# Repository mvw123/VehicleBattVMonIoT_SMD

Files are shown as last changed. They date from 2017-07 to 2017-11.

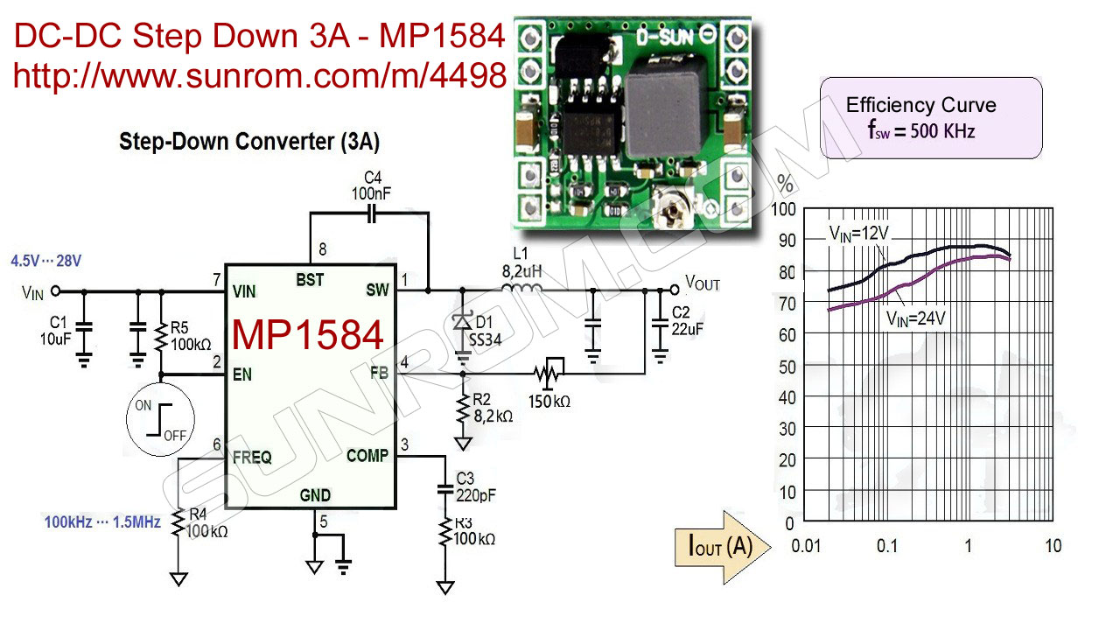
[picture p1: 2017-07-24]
CADB/MP1584-schematic.jpg

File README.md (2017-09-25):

Vehicle battery voltage monitor IoT SMD
=======================================

Vehicle battery voltage monitor IoT. Measures the voltage of a 12V car battery. Sends this to a receiver device which pushes the data to the cloud.

This PCB is designed to fit in the car strapped between the battery terminals. It uses either a LoRA RFM95 module, or a sub Ghz modules RFM69HCW module. Other parts of the design mostly use low cost modules to reduce the hand assembly time. Some through hole components, SMD 0805 and SMD diodes require hand assembly.

Designed using Eagle cad 7.5.0 light.

Incorporates support for:- 
* Arduino Pro Mini, 3.3V, 8MHz version only. (5V version will damage circuit)
* RFM69HCW or RFM95W/96W/97W/98W module
* SMA 50 ohm antenna connector
* 16 bit ADC module TI ADS1115
* Sensirion SHT31 temperature/humidity sensor module
* DC-DC converter
* Fuse and reverse voltage protection
* [Optional] RGB LED to visually indicate voltage levels
* [Optional] EUI-64 LoRA node identity chip for debug
* [Optional] Winbond flash storage
* [Optional] OLED display interface for debug purposes
* [Optional] HM-10 Bluetooth LE module carrier footprint

CAD B - [WIP]
=============

Not released yet, needs CAD updates. 

CAD A - [FAULTY]
===========================

Board has CAD issues, see issues list. needed some wiring and re-work. 
Board released for manufacture 3 Aug 2017
Software partially written

MVW
www.guvvy.co.uk

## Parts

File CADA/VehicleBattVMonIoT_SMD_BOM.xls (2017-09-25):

Qty | Value | Device | Package | Parts | Description | MF | MPN | OC_FARNELL | Price | OC_NEWARK | PROD_ID | Digikey | Other | Price
3 | 100uF, 25V, 85C | CAP_POLPTH1 | CPOL-RADIAL-100UF-25V | C1, C4, C5 | Capacitor Polarized | MULTICOMP | MCUMR25V107M8X5 | 1870940
9 | 1uF, 0805, 25V, X5R | C-EUC0805 | C0805 | C2, C3, C6, C7, C9, C10, C11, C12, C13 | CAPACITOR, European symbol | MULTICOMP | MC0805X105K250CT | 2320832
1 | 1NF, 0805, 16V, X5R |  | C0805 | C8 | CAPACITOR, European symbol | MULTICOMP | MCSH21B102K160CT | 1856432
1 | MBRA340T3 | MBRA340T3 | SMA | D1 | Surface Mount Schottky Power Rectifier | ON SEMICONDUCTOR | MBRA340T3G | 1431078
1 | 1N4148W | DIODESOD-323F | SOD-323F | D11 | Diode | MULTICOMP | 1N4148WS. | 1466524
8 | MBR0520LT | MBR0520LT | SOD123 | D2, D3, D4, D5, D6, D7, D8, D10 | SCHOTTKY BARRIER RECTIFIER | Taiwan semi | B0520LW | 1863141 | £0.028 |  |  |  | BAT42W+ at farnell is £0.069 in 10 off qty if the series power diode can be dropped (which is can)
1 | WS2812B | WS2812B | WS2812B | D9 | WS2812B - Intelligent control LED integrated light source |  |  | - |  |  |  |  | See ebay
1 | Multicomp MC36219 | PTCFUSE-1812 | 1812 | F1 | PTC fuses, resettable thermistors | MULTICOMP | MC36219. | 1861164
1 | 24AA02E64 | 24AA00OT | SOT23-5L | IC1 | Serial EEPROM | MICROCHIP | 24AA00T-I/OT | 1331264 |  | 89H3038
1 | LM1117 | V_REG_LM1117SOT223 | SOT223 | IC3 | Voltage Regulator LM1117 | STMICROELECTRONICS | LD1117S33TR | 1202826 |  |  | VREG-08170
1 | HM-10 MODULE | CON_HEADER_1X06-SMD-RIGHT-ANGLED | M1X6_MALE_RIGHT_ANGLED_SMD | J1 |  |  |  | - |  |  |  |  | See ebay, only buy original was 2 crystals
1 | SHT31 MODULE | PINHD-1X4 | 1X04 | JP1 |  |  |  | - |  |  |  |  | See ebay
1 | OLED MODULE | PINHD-1X4 | 1X04 | JP2 |  |  |  | - |  |  |  |  | See ebay
1 | MSS7341 | MSS7341 | MSS7341 | L1 |  | COILCRAFT | MSS7341-683MLD | 2288678
1 | ARDUINO-PRO-MINI-3.3V#APC | ARDUINO-PRO-MINI-3.3V#APC | ARDUINO-PRO-MINI#APC | M1 | Arduino Pro Mini (and compatible devices) with angle programming connector |  |  | - |  |  |  |  | See ebay
6 | 10k, 5% | R-EU_R0805 | R0805 | R1, R2, R3, R4, R6, R7 | RESISTOR, European symbol | MULTICOMP | MC01W0805510K | 9333720
2 | 22k, 1% | R-EU_R0805 | R0805 | R10, R11 | RESISTOR, European symbol | WELWYN | WCR0805-22KFI | 1099809
1 | 1k, 5% | R-EU_R0805 | R0805 | R5 | RESISTOR, European symbol | WELWYN | WCR0805-1K0FI | 1099800
2 | 100k, 1% | R-EU_R0805 | R0805 | R8, R9 | RESISTOR, European symbol | YAGEO (PHYCOMP) | RC0805FR-07100KL | 9237879
1 | ADS1115 MODULE | MA10-1W | MA10-1W | SV1 |  |  |  | - |  |  |  |  | See ebay
1 | DC-DC-STEP-DOWN-MP1584 | DC-DC-STEP-DOWN-MP1584 | DC-DC-STEP-DOWN-MP1584 | U1 | DC/DC Step-Down Regulator based on MP1584 chip |  |  | - |  |  |  |  | See ebay
1 | RFM9xW | RFM9xW | RFM69HCW-XXXS2 | U3 | RFM69HCW, or LoRA RFM9xW. Choose frequency appropriate for your location | Hope RF | Frequency dependent | - |  |  |  |  | See list at bottom of BOM
1 | W25Q80DVSNIG | SPI_FLASH-X25XXSMD | SO08 | U4 | 8pin SPI Flash series x25xx. Works with devices like W25X32 and BR25L32, may need software driver for specific part | Winbond | W25Q80DVSNIG | not available at farnell |  |  |  | W25Q80DVSNIG CT-ND | See ebay
1 | BU-SMA-G | BU-SMA-G | BU-SMA-G | X1 | FEMALE SMA CONNECTOR | AMP - TE CONNECTIVITY | 5-1814400-1 | 1248989
 | Antenna |  |  | Mech1 | Frequency dependent |  |  |  |  |  |  |  | See ebay, ali express etc
 | Case |  |  | Mech2 | Off the shelf, donor, or custom check fire retardancy ratings |  |  |  |  |  |  |  | Donor: Maplin Electronics N70NF | £0.99
 | Screws M2.5 | DTRNSE 1207 M2.5 10 |  | Mech3 | 10mm nylon M2.5 screw |  |  | 2472698
 | Posts | DTRDLCBST-1-01 |  | Mech4 | The DTRDLCBST-1-01 is a PCB Mini Support Post made of PA 66. 2.54 ±0.08mm Hole diameter 1.63mm Panel thickness |  |  | 2472885
 | Washer | DTRNWE 34815 M2.5 |  | Mech5 | M2.5 washer |  |  | 2472663
 | Nuts | Duratool 1110025 |  | Mech6 | Nylon nut pack of 50 |  |  | 7016931
 | Wire |  |  | Mech7 | Automotive wire 2mm^2, check fire retardancy ratings |  |  |  |  |  |  |  | Ebay or Source from hackspace initially
 | Crimps |  |  | Mech7 | Size? |  |  |  |  |  |  |  | B&Q for initial samples
 | Crimp tool |  |  | Mech8 | Do I have one in old toolboxes??? |  |  |  |  |  |  |  | B&Q for initial samples
0 | TP_1MM_TH";"TP_1MM_TH";"TP_1MM_TH | TP1, TP2, TP3, TP4, TP5, TP6, TP7, TP8 | Bare copper test points for troubleshooting or ICT |  |  | unknown
0 | POS | 3,81/1,4 | 3,81/1,4 | PAD1 | THROUGH-HOLE PAD
0 | NEG | 3,81/1,4 | 3,81/1,4 | PAD2 | THROUGH-HOLE PAD
0 | MOUNT-HOLE2.8 | MOUNT-HOLE2.8 | 2,8 | H2, H3, H4, H5 | MOUNTING HOLE with drill center marker
 | 868MHz
 | Antenna
 | RFM95W-868S2

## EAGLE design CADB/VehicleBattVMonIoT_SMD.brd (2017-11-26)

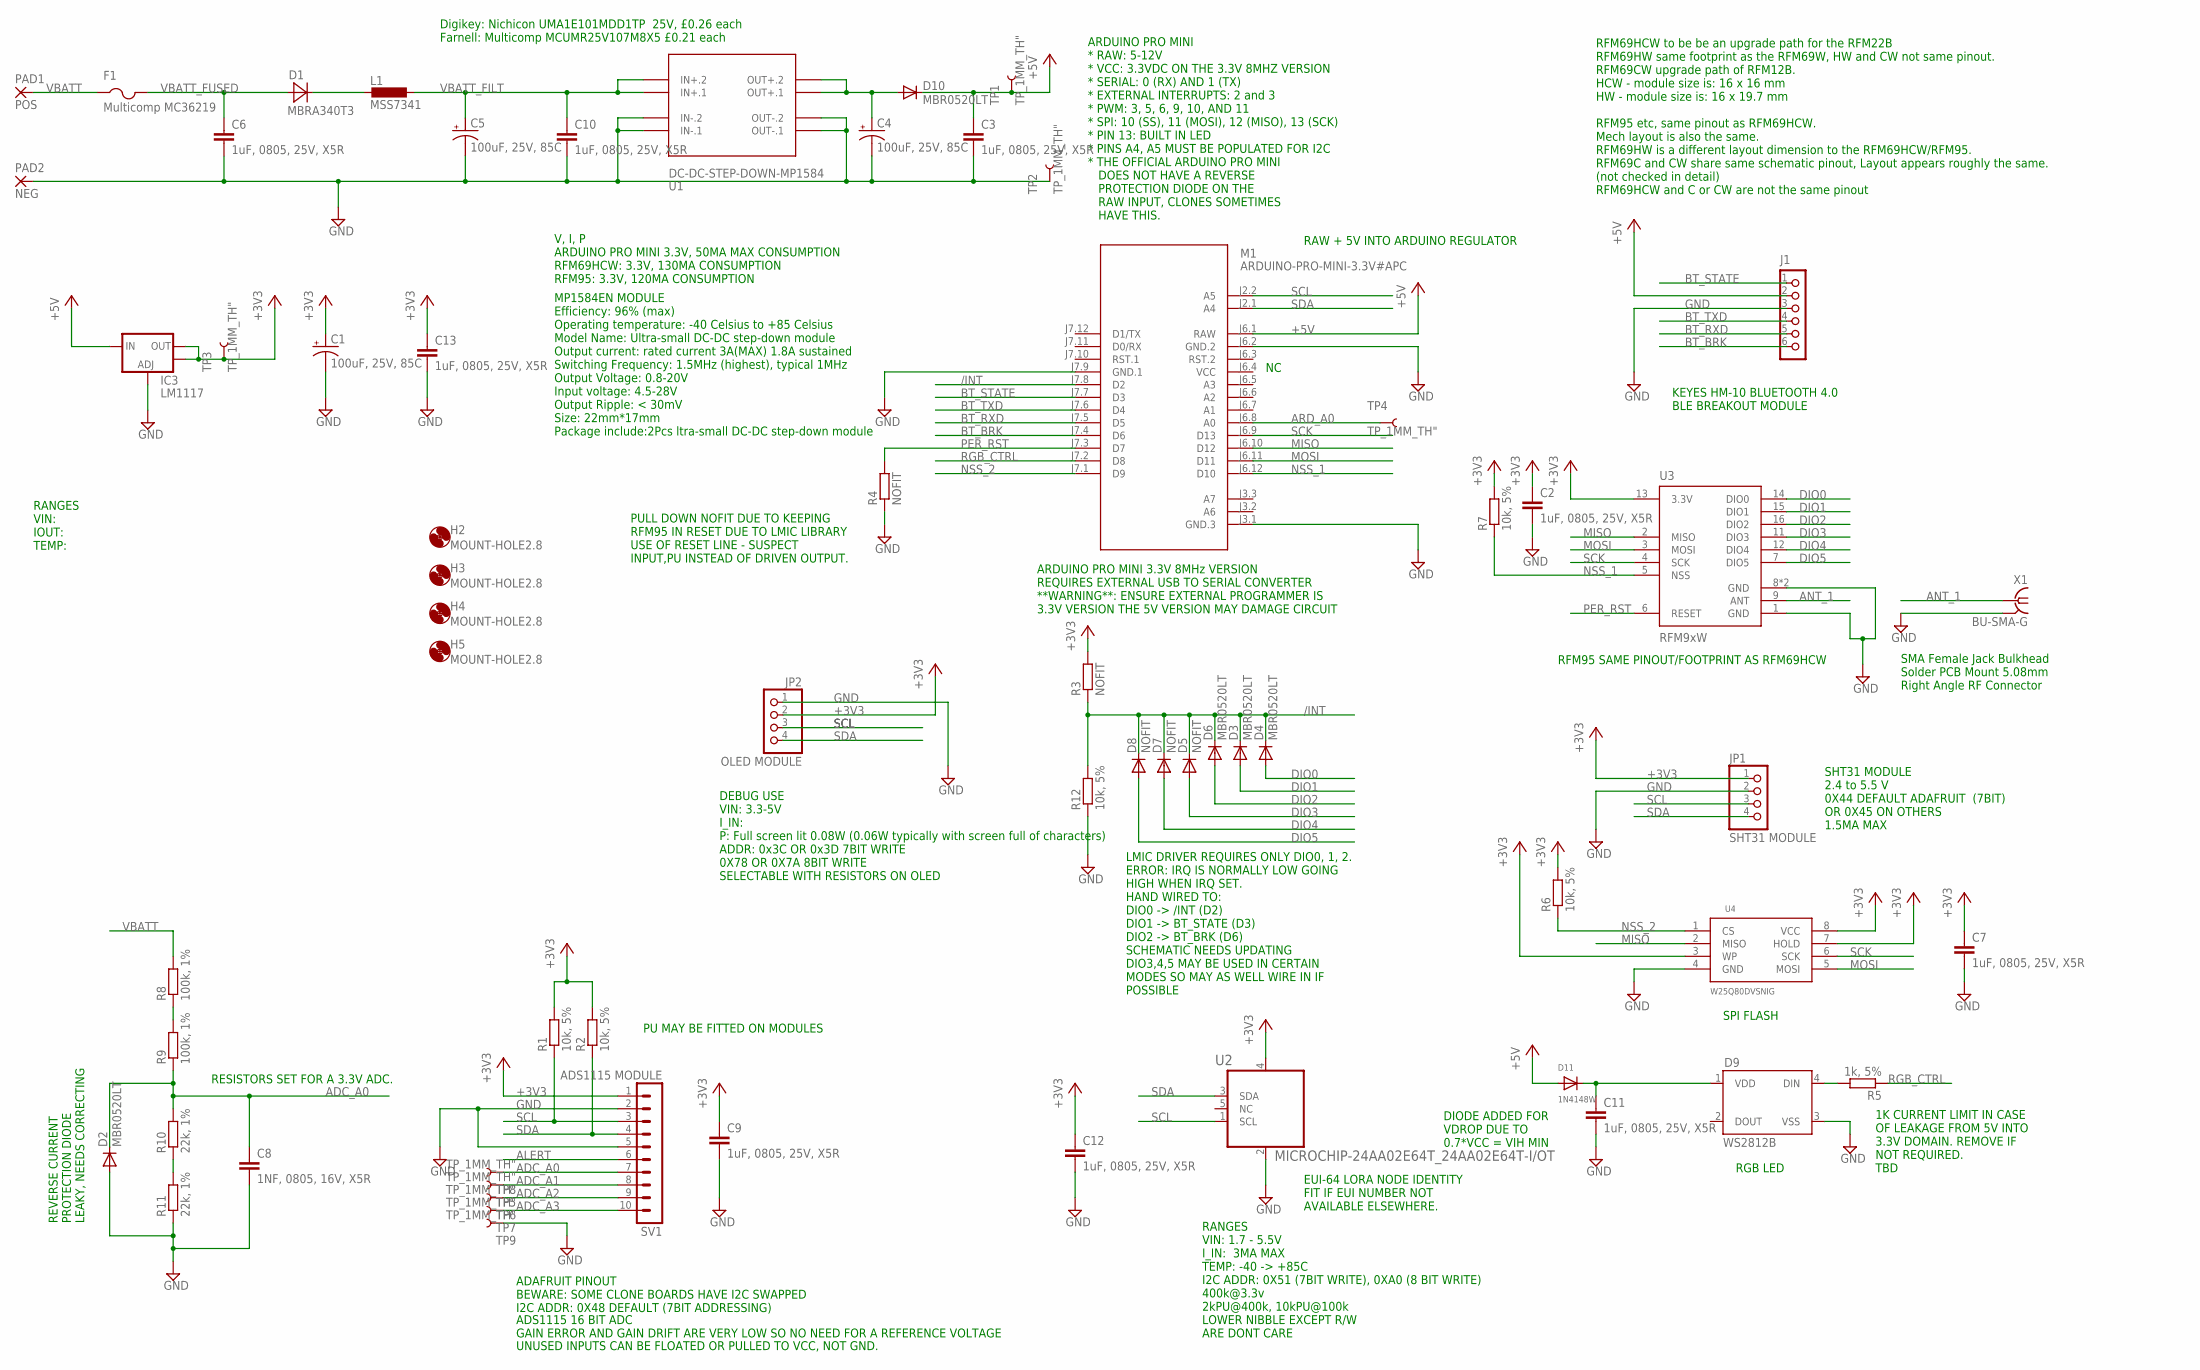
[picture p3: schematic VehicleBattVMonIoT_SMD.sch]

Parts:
C1, C4, C5: 100uF, 25V, 85C; CPOL-RADIAL-100UF-25V; MPN MCUMR25V107M8X5
C2, C3, C6, C7, C9, C10, C11, C12, C13: 1uF, 0805, 25V, X5R; C0805; MPN MC0805X105K250CT
C8: 1NF, 0805, 16V, X5R; C0805; MPN MCSH21B102K160CT
D1: MBRA340T3; SMA; MPN MBRA340T3G
D2, D3, D4, D6, D10: MBR0520LT; SOD123; MPN B0520LW-7-F
D5, D7, D8: NOFIT; SOD123; MPN B0520LW-7-F
D9: WS2812B
D11: 1N4148W; SOD-323F; MPN 1N4148WS.
F1: Multicomp MC36219; 1812; MPN MC36219.
H2, H3, H4, H5: MOUNT-HOLE2.8; 2,8
IC3: LM1117; SOT223; MPN LD1117S33TR
J1: HM-10 MODULE; M1X6_MALE_RIGHT_ANGLED_SMD
JP1: SHT31 MODULE; 1X04
JP2: OLED MODULE; 1X04
L1: MSS7341; MPN MSS7341-683MLD
M1: ARDUINO-PRO-MINI-3.3V#APC; ARDUINO-PRO-MINI#APC
PAD1: POS; 3,81/1,4
PAD2: NEG; 3,81/1,4
R1, R2, R6, R7, R12: 10k, 5%; R0805; MPN MC01W0805510K
R3, R4: NOFIT; R0805; MPN MC01W0805510K
R5: 1k, 5%; R0805; MPN WCR0805-1K0FI
R8, R9: 100k, 1%; R0805; MPN RC0805FR-07100KL
R10, R11: 22k, 1%; R0805; MPN WCR0805-22KFI
SV1: ADS1115 MODULE; MA10-1W
TP1, TP2, TP3, TP4, TP5, TP6, TP7, TP8, TP9: TP_1MM_TH"; TP_1MM_TH
U1: DC-DC-STEP-DOWN-MP1584
U2: MICROCHIP-24AA02E64T_24AA02E64T-I/OT; MICROCHIP-24AA02E64T_SOT95P270X145-5N
U3: RFM9xW; RFM69HCW-XXXS2
U4: W25Q80DVSNIG; SO08
X1: BU-SMA-G; MPN 5-1814400-1

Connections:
+3V3: C1.1 (+), C2.1, C7.1, C9.1, C12.1, C13.1, IC3.2 (OUT), IC3.4 (OUT), JP1.1, JP2.2, R1.2, R2.2, R3.2, R6.2, R7.2, SV1.1, TP3.P$1, U2.4 (VCC), U3.13 (3.3V), U4.3 (WP), U4.7 (HOLD), U4.8 (VCC)
+5V: C3.1, D10.C, D11.A, IC3.3 (IN), J1.2, M1.J6.1 (RAW), TP1.P$1
/INT: D3.C, D4.C, D5.C, D6.C, D7.C, D8.C, M1.J7.8 (D2), R3.1, R12.2
ADC_A0: C8.1, D2.C, R9.1, R10.2, SV1.7, TP8.P$1
ADC_A1: SV1.8, TP5.P$1
ADC_A2: SV1.9, TP6.P$1
ADC_A3: SV1.10, TP7.P$1
ALERT: SV1.6
ANT_1: U3.9 (ANT), X1.1
ARD_A0: M1.J6.8 (A0), TP4.P$1
BT_BRK: J1.6, M1.J7.4 (D6)
BT_RXD: J1.5, M1.J7.5 (D5)
BT_STATE: J1.1, M1.J7.7 (D3)
BT_TXD: J1.4, M1.J7.6 (D4)
DIO0: D4.A, U3.14 (DIO0)
DIO1: D3.A, U3.15 (DIO1)
DIO2: D6.A, U3.16 (DIO2)
DIO3: D5.A, U3.11 (DIO3)
DIO4: D7.A, U3.12 (DIO4)
DIO5: D8.A, U3.7 (DIO5)
GND: C1.2 (-), C2.2, C3.2, C4.2 (-), C5.2 (-), C6.2, C7.2, C8.2, C9.2, C10.2, C11.2, C12.2, C13.2, D2.A, D9.3 (VSS), IC3.1 (ADJ), J1.3, JP1.2, JP2.1, M1.J3.1 (GND.3), M1.J6.2 (GND.2), M1.J7.9 (GND.1), PAD2.1, R4.1, R11.1, R12.1, SV1.2, SV1.5, TP2.P$1, TP9.P$1, U1.IN-.1, U1.IN-.2, U1.OUT-.1, U1.OUT-.2, U2.2 (VSS), U3.1 (GND), U3.8 (GND), U3.10 (GND), U4.4 (GND), X1.2, X1.3 (2), X1.4 (2), X1.5 (2)
MISO: M1.J6.10 (D12), U3.2 (MISO), U4.2 (MISO)
MOSI: M1.J6.11 (D11), U3.3 (MOSI), U4.5 (MOSI)
unnamed: C11.1, D9.1 (VDD), D11.C
unnamed: D1.C, L1.1
unnamed: R10.1, R11.2
unnamed: R8.1, R9.2
unnamed: C4.1 (+), D10.A, U1.OUT+.1, U1.OUT+.2
unnamed: D9.4 (DIN), R5.2
NSS_1: M1.J6.12 (D10), R7.1, U3.5 (NSS)
NSS_2: M1.J7.1 (D9), R6.1, U4.1 (CS)
PER_RST: M1.J7.3 (D7), R4.2, U3.6 (RESET)
RGB_CTRL: M1.J7.2 (D8), R5.1
SCK: M1.J6.9 (D13), U3.4 (SCK), U4.6 (SCK)
SCL: JP1.3, JP2.3, M1.J2.2 (A5), R1.1, SV1.3, U2.1 (SCL)
SDA: JP1.4, JP2.4, M1.J2.1 (A4), R2.1, SV1.4, U2.3 (SDA)
VBATT: F1.1, PAD1.1, R8.2
VBATT_FILT: C5.1 (+), C10.1, L1.2, U1.IN+.1, U1.IN+.2
VBATT_FUSED: C6.1, D1.A, F1.2
VCC: M1.J6.4 (VCC)

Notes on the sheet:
RFM69HCW to be be an upgrade path for the RFM22B RFM69HW same footprint as the RFM69W, HW and CW not same pinout. RFM69CW upgrade path of RFM12B. HCW - module size is: 16 x 16 mm HW - module size is: 16 x 19.7 mm RFM95 etc, same pinout as RFM69HCW. Mech layout is also the same. RFM69HW is a differe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
ARDUINO PRO MINI 3.3V 8MHz VERSION REQUIRES EXTERNAL USB TO SERIAL CONVERTER **WARNING**: ENSURE EXTERNAL PROGRAMMER IS 3.3V VERSION THE 5V VERSION MAY DAMAGE CIRCUIT
ADS1115 16 BIT ADC GAIN ERROR AND GAIN DRIFT ARE VERY LOW SO NO NEED FOR A REFERENCE VOLTAGE
RFM95 SAME PINOUT/FOOTPRINT AS RFM69HCW
ADAFRUIT PINOUT BEWARE: SOME CLONE BOARDS HAVE I2C SWAPPED I2C ADDR: 0X48 DEFAULT (7BIT ADDRESSING)
ARDUINO PRO MINI * RAW: 5-12V * VCC: 3.3VDC ON THE 3.3V 8MHZ VERSION * SERIAL: 0 (RX) AND 1 (TX) * EXTERNAL INTERRUPTS: 2 and 3 * PWM: 3, 5, 6, 9, 10, AND 11 * SPI: 10 (SS), 11 (MOSI), 12 (MISO), 13 (SCK) * PIN 13: BUILT IN LED * PINS A4, A5 MUST BE POPULATED FOR I2C * THE OFFICIAL ARDUINO PRO MINI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
UNUSED INPUTS CAN BE FLOATED OR PULLED TO VCC, NOT GND.
MP1584EN MODULE Efficiency: 96% (max) Operating temperature: -40 Celsius to +85 Celsius Model Name: Ultra-small DC-DC step-down module Output current: rated current 3A(MAX) 1.8A sustained Switching Frequency: 1.5MHz (highest), typical 1MHz Output Voltage: 0.8-20V Input voltage: 4.5-28V Output Rippl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
V, I, P ARDUINO PRO MINI 3.3V, 50MA MAX CONSUMPTION RFM69HCW: 3.3V, 130MA CONSUMPTION RFM95: 3.3V, 120MA CONSUMPTION
REVERSE CURRENT PROTECTION DIODE LEAKY, NEEDS CORRECTING
KEYES HM-10 BLUETOOTH 4.0 BLE BREAKOUT MODULE
Digikey: Nichicon UMA1E101MDD1TP 25V, £0.26 each Farnell: Multicomp MCUMR25V107M8X5 £0.21 each
SHT31 MODULE 2.4 to 5.5 V 0X44 DEFAULT ADAFRUIT (7BIT) OR 0X45 ON OTHERS 1.5MA MAX
DEBUG USE VIN: 3.3-5V I_IN: P: Full screen lit 0.08W (0.06W typically with screen full of characters) ADDR: 0x3C OR 0x3D 7BIT WRITE 0X78 OR 0X7A 8BIT WRITE SELECTABLE WITH RESISTORS ON OLED
DIODE ADDED FOR VDROP DUE TO 0.7*VCC = VIH MIN
1K CURRENT LIMIT IN CASE OF LEAKAGE FROM 5V INTO 3.3V DOMAIN. REMOVE IF NOT REQUIRED. TBD
RANGES VIN: IOUT: TEMP:
SPI FLASH
RGB LED
EUI-64 LORA NODE IDENTITY FIT IF EUI NUMBER NOT AVAILABLE ELSEWHERE.
PU MAY BE FITTED ON MODULES
RANGES VIN: 1.7 - 5.5V I_IN: 3MA MAX TEMP: -40 -> +85C I2C ADDR: 0X51 (7BIT WRITE), 0XA0 (8 BIT WRITE) 400k@3.3v 2kPU@400k, 10kPU@100k LOWER NIBBLE EXCEPT R/W ARE DONT CARE
SMA Female Jack Bulkhead Solder PCB Mount 5.08mm Right Angle RF Connector
RAW + 5V INTO ARDUINO REGULATOR
LMIC DRIVER REQUIRES ONLY DIO0, 1, 2. ERROR: IRQ IS NORMALLY LOW GOING HIGH WHEN IRQ SET. HAND WIRED TO: DIO0 -> /INT (D2) DIO1 -> BT_STATE (D3) DIO2 -> BT_BRK (D6) SCHEMATIC NEEDS UPDATING DIO3,4,5 MAY BE USED IN CERTAIN MODES SO MAY AS WELL WIRE IN IF POSSIBLE
PULL DOWN NOFIT DUE TO KEEPING RFM95 IN RESET DUE TO LMIC LIBRARY USE OF RESET LINE - SUSPECT INPUT,PU INSTEAD OF DRIVEN OUTPUT.
RESISTORS SET FOR A 3.3V ADC.

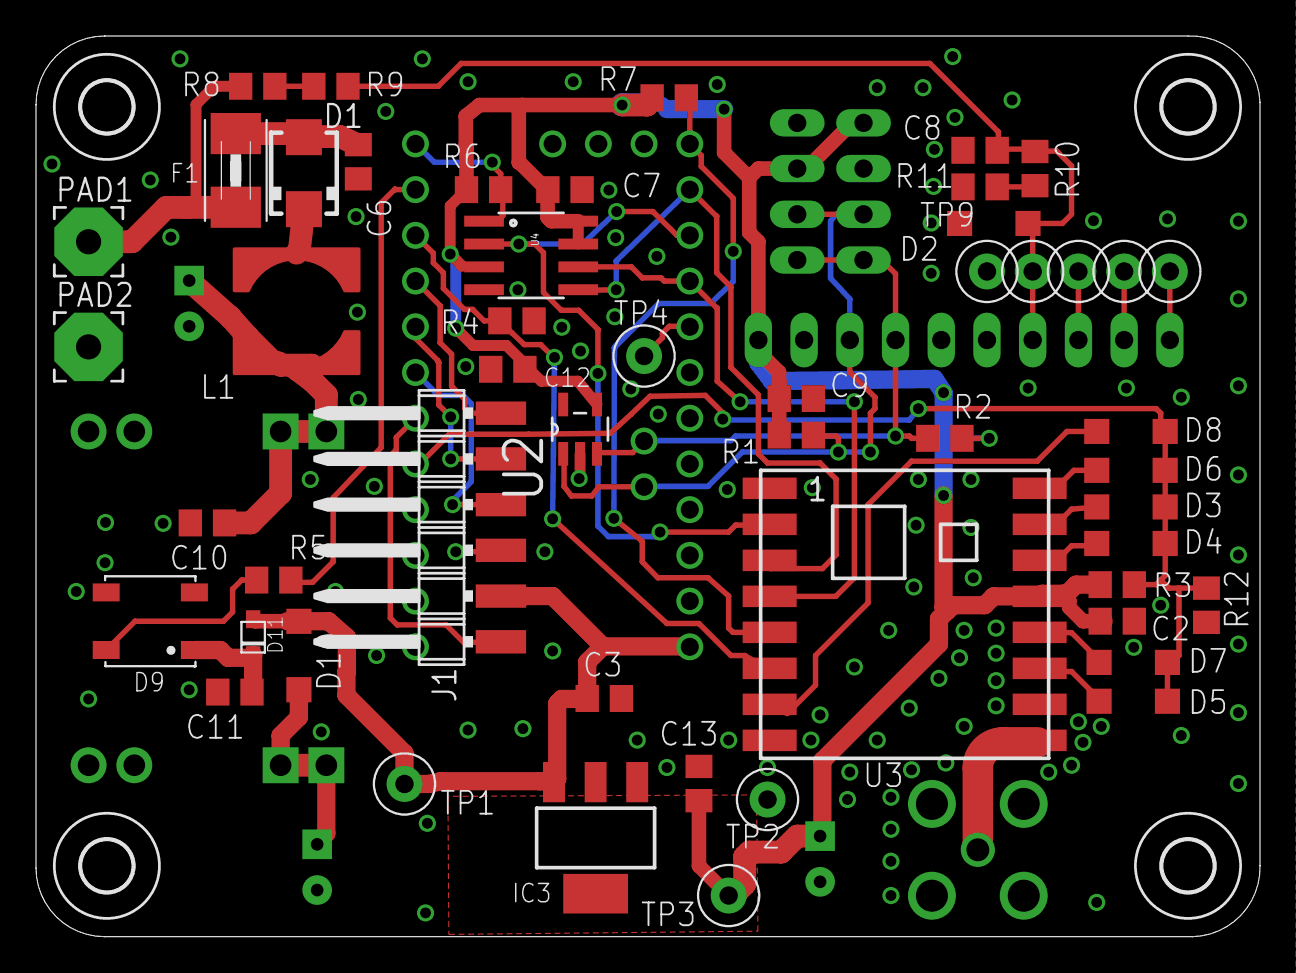
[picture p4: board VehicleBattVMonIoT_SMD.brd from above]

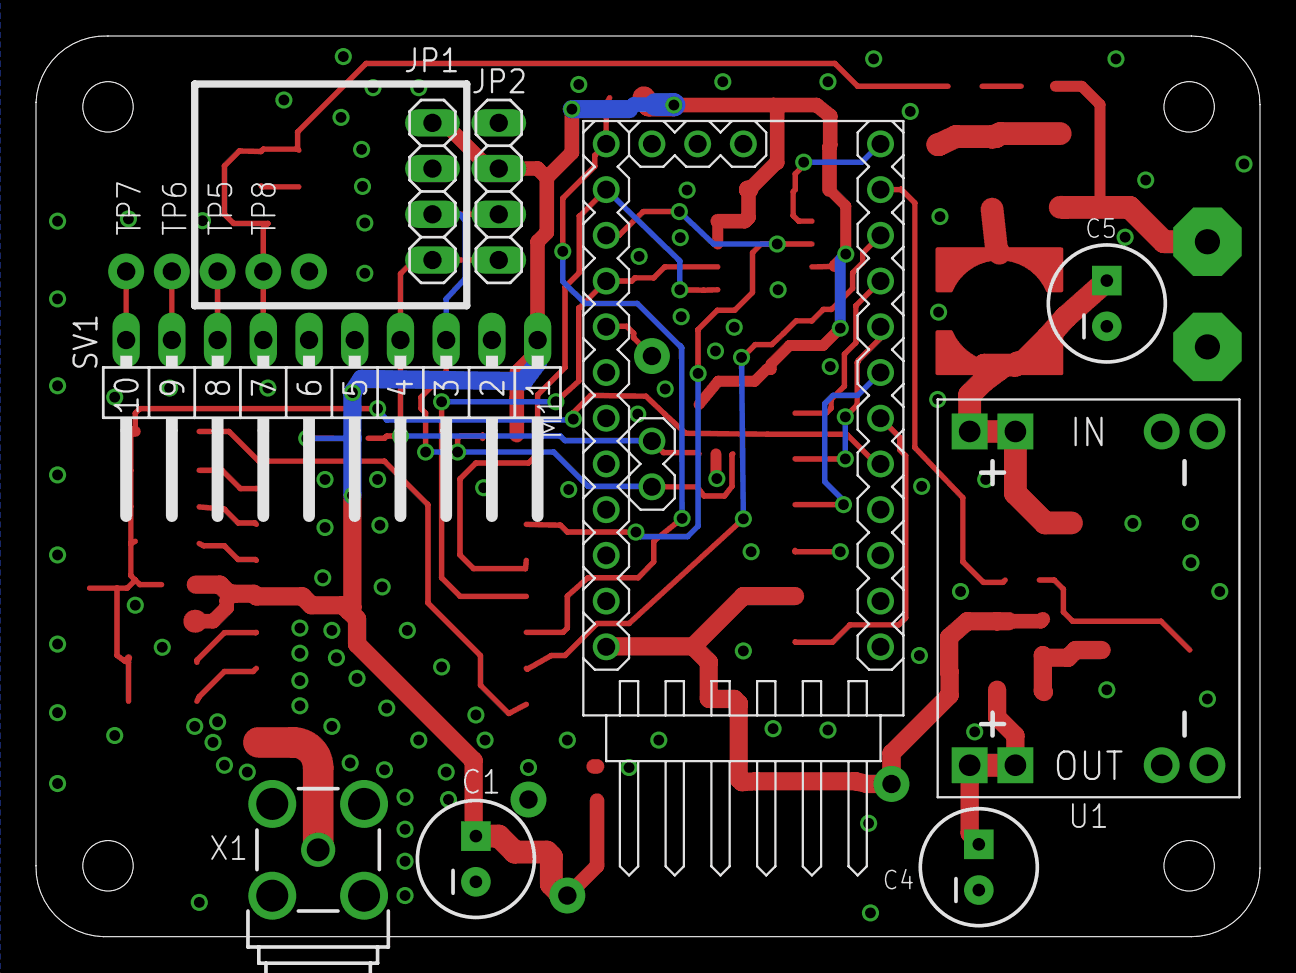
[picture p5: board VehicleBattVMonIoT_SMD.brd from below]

Board: 2 copper layers, 68.0 x 50.0 mm, 64 parts (9 on the bottom side), 38 nets.

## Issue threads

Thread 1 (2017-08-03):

Issues noted after release of CAD A

mvw123, 2017-08-03:
Issues noted after release of CAD A, or items left until CAD B:
- Component values need adding for all parts.
- Logo
- Name
- Is it open source?
- Re-number parts
- Outlines for modules need tidying
- Voltage, current, power, temperature ranges need adding for all parts
- Confirm it can operate over required voltage and automotive temperature ranges
- Check mount holes are acceptable when mounting posts arrive.
- Check clearance on all modules
- 1K ohm to DIN on RGB LED may not be needed, test on first CAD
- Test to see if the DC-DC can be removed and replaced with a linear reg without thermal issues.
- Confirm fit in the enclosure
- Add text to PCB to indicate which RF modules are supported.

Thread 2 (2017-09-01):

LoRa module issue

mvw123, 2017-09-01:
No comms via lora module

mvw123, 2017-09-01:
10k PD on reset line was pulling reset line down to 1v.
Tested with a driven output which worked.
no fitted 10k pulldown resistor on schematic and test board

Closed 2017-09-01.

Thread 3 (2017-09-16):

ADC input voltage potential divider resistor values and tolerances need improving.

mvw123, 2017-09-16:
- Changing from 2x100k to 2 x 22k 1% resistors to 10k and 2k 0.1% resistors reduced the error reading at the 12v input down to 8.5mV from around 90mV with 1% resistors and down to approx 1mV at the A0 input. Also noted that one DVM loaded the A0 input so needed to use 6.5 digit meter. suggest using
10k and 2.91k 0.1% resistors which can be had for less than 5pence each on Farnell.
This provides full range at 18V max input voltage.
2138951
http://uk.farnell.com/w/c/passive-components/resistors-fixed-value/chip-smd-resistors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
2.94k ohm 0.1% 0805 £0.0497 , 10 MOQ
1469857
http://uk.farnell.com/w/c/passive-components/resistors-fixed-value/chip-smd-resistors?resistance=10kohm|2.94kohm&resistor-case-style=0805-2012-metric-&range=exc-obs|exc-direct-ship|inc-in-stock&comp=inc-rohs&st=2.91k+ohm+resistor
£0.0284 at MOQ 10

Note: 2000 ohm may be better  instead of 2.94k for 24v batteries

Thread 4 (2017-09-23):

EUI64 device is not present on I2C bus

mvw123, 2017-09-23:
EUI64 device is not present on I2C bus
Should be at address 0x50 (7bit)

Scanning...
I2C device found at address 0x3C  ! OLED
I2C device found at address 0x44  ! SHT31
I2C device found at address 0x48  ! ADS1115 ADC
done

schema looks ok, check PU resistors and timings

mvw123, 2017-10-30:
still faulty
Lowered pullup resistance to approx 3k, no joy
changed part, still no comms
scope shows nack isn't being reported when device addressed.
changed part. no joy
checked schematic and footprint, looking good.

ToDo
1) try a lower pullup resistor value
2) study datasheets I2C addressing modes to see what may be happening.

mvw123, 2017-11-10:
Wrong part fitted. A 24aa00 part was ordered instead of 24aa02.
Believe this is because a 24aa00 footprint was obtained for the SOT23-5
Farnell no longer stock the EUI-64 part.  2345567, Microchip 24AA02E64T-I/OT,  SOT23-5
Schematic and boards need correcting

mvw123, 2017-11-10:
Changed part in schematic and layout.
In theory the part should be the same pinout though so just replacing the part with the correct one will suffice for testing.
Close once new parts obtained and tested.

mvw123, 2017-12-13:
those parts are not available at farnell, though are available at digikey.
alternative 6 pin parts obtained from farnell which require a different footprint. may be best to change over to these new parts which are slightly more expensive but show up at more distributors.

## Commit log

2017-07-24 Vehicle battery voltage monitor IoT SMD version
    Vehicle battery voltage monitor IoT SMD version with two arduino pro
    mini boards, committing to backup before removing one
    [VehicleBattVMonIoT_SMD.brd, VehicleBattVMonIoT_SMD.sch]
2017-07-24 updated arduino pro mini symbol to allow flood
    [VehicleBattVMonIoT_SMD.brd, VehicleBattVMonIoT_SMD.sch]
2017-08-03 CAD A release for manufacture
    Released for manufacture at OSH park
    [VehicleBattVMonIoT_SMD.brd, VehicleBattVMonIoT_SMD.sch]
2017-08-03 Minor updates to schematic and pcb
    [VehicleBattVMonIoT_SMD.brd, VehicleBattVMonIoT_SMD.sch]
2017-09-25 Latest CAD B and re-arrange structure
    seperate directory for CADA CADB.
    [VehicleBattVMonIoT_SMD.brd, VehicleBattVMonIoT_SMD.csv, VehicleBattVMonIoT_SMD.sch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]
2017-11-26 minor updates
    [VehicleBattVMonIoT_SMD.brd, VehicleBattVMonIoT_SMD.sch]

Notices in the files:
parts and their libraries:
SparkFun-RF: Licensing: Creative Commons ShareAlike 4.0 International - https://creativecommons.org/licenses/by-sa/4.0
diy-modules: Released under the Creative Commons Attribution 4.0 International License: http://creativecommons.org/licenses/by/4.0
